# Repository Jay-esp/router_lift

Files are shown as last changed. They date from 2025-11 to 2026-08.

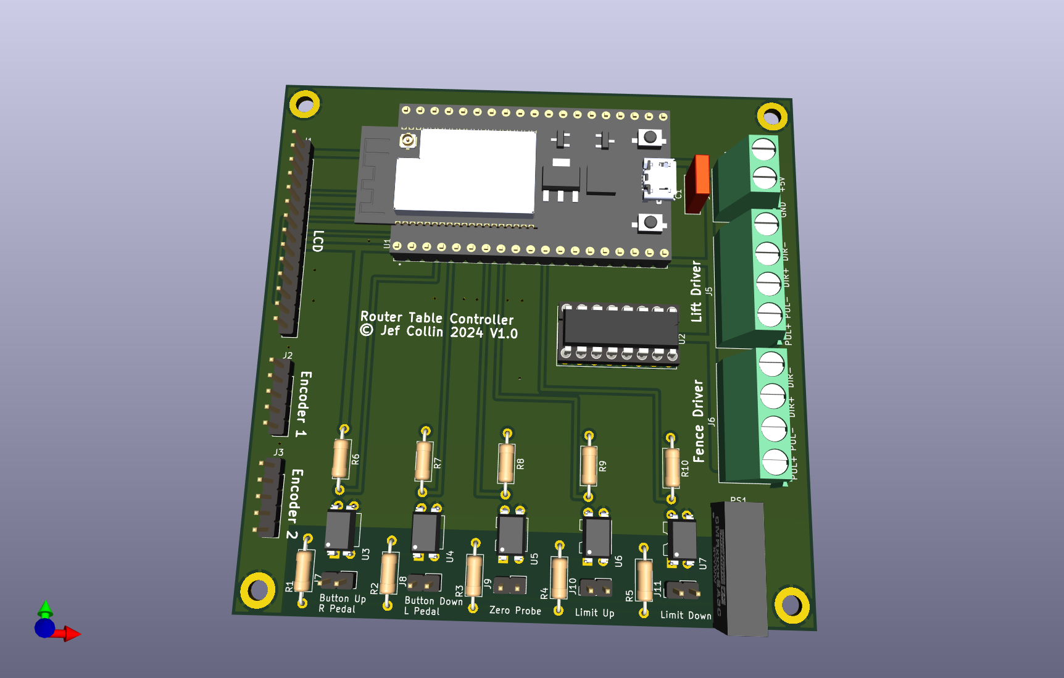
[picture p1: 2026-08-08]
router_table_1_0.png

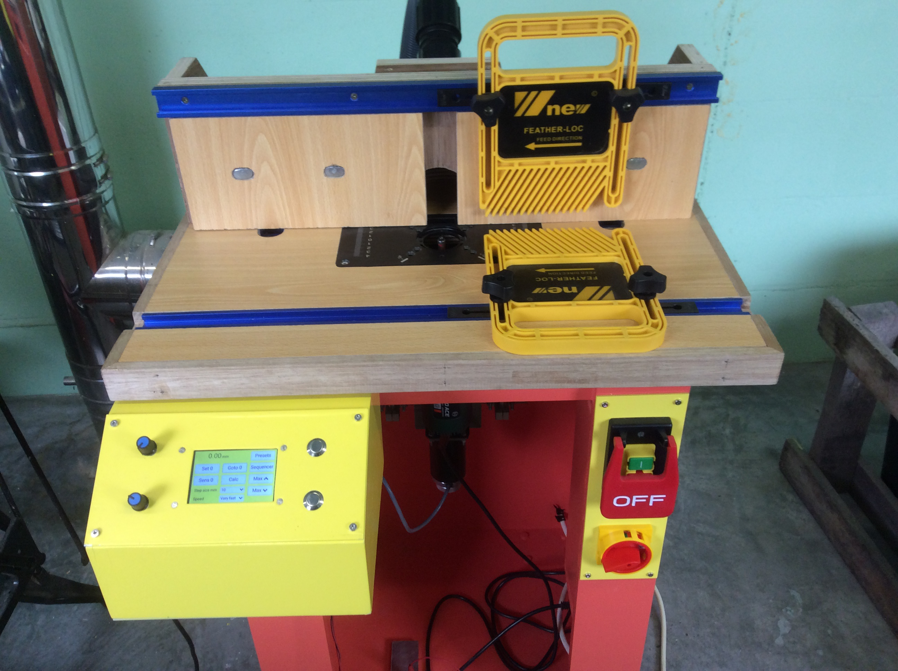
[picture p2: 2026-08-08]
IMG_5953.JPG

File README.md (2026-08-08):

# router_lift
Router table with electronic router lift using ESP32 and 3.5" touch screen

In 2020 I designed and built this router table with an electronic router lift. Since then i upgraded the electronics and rewrote the software, i made a YT video for it and published the design.

https://youtu.be/Isq1No5Fesk

Main features:

- Z height calibration using a sense block
- absolute positioning
- adjustable step size and plunge rate
- 25 presets
- 5 x 5 step sequencer
- dial a position of calculate a position

The electronics has a provision for a second stepper motor in case i later want to redesign it with a electronic fence.

Since all parts are made by hand there are no precise mechanical drawings but I included some freecad concept drawings.

Development in the Arduino 1 IDE in portable mode, uses FastAccelStepper 1.2.7 stepper driver library, LovyanGFX 1.2.9 graphics driver library and LVGL 9.5.0 GUI library.

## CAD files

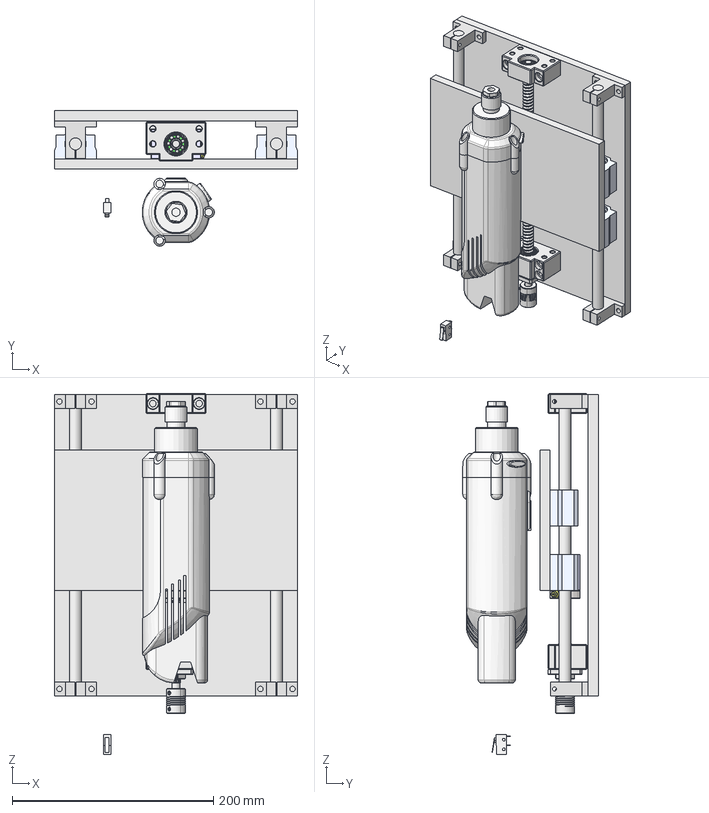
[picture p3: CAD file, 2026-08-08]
frees_lift2.FCStd
242.0 x 134.8 x 359.2 mm
SK12 SHAFT HOLDER
SK12 SHAFT HOLDER001
SK12 SHAFT HOLDER002
SK12 SHAFT HOLDER003
SC12UU
SC12UU001
SC12UU002
SC12UU003
BF10
BK10
SFU Ball Nut_1204-3
SFU1204 Washer Front
SFU1204 Washer Back
Grease Nipple A_A M6x1.00
Steel Ball_O 2.50
socket set screw cone point_iso_ISO 4027 - M3 x 5-C
socket set screw cone point_iso_ISO 4027 - M3 x 5-C001
socket set screw cone point_iso_ISO 4027 - M3 x 2.5-C
socket set screw cone point_iso_ISO 4027 - M3 x 2.5-C001
SFU1204-300_1204-300
CNC-F_N_CHINA_Domek kulickove matice
CHINA_Spojka pruzna_D19L25_6,35x8
LowerCap
Spilneus
Body-Grey
Body-Red
MICROSWITCH-NO

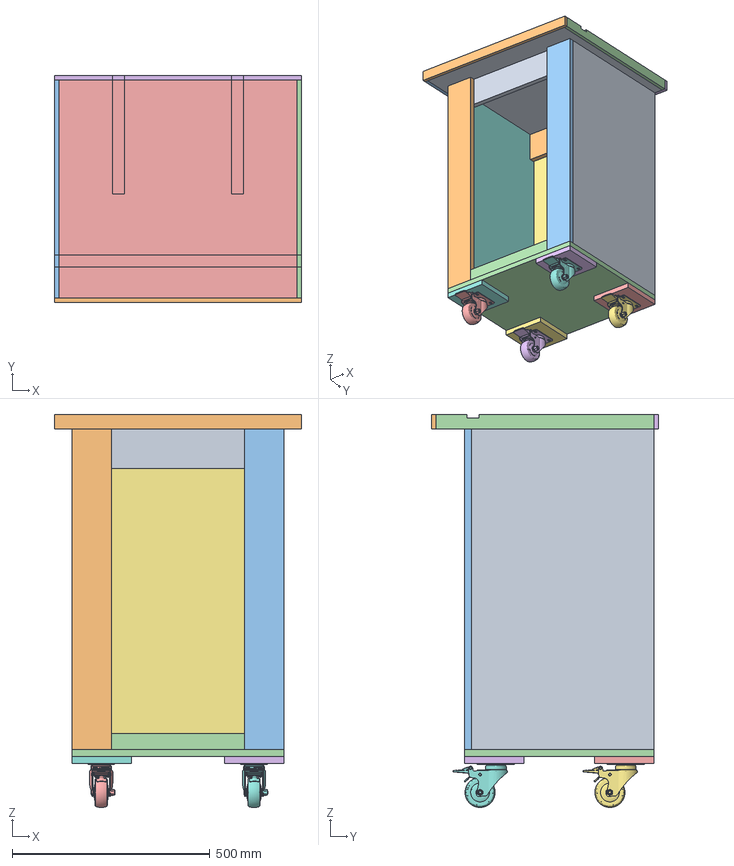
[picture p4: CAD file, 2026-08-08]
freestafel2.FCStd
624.0 x 574.0 x 992.5 mm
sSTL
sSTL002
sSTL003
sSTL001

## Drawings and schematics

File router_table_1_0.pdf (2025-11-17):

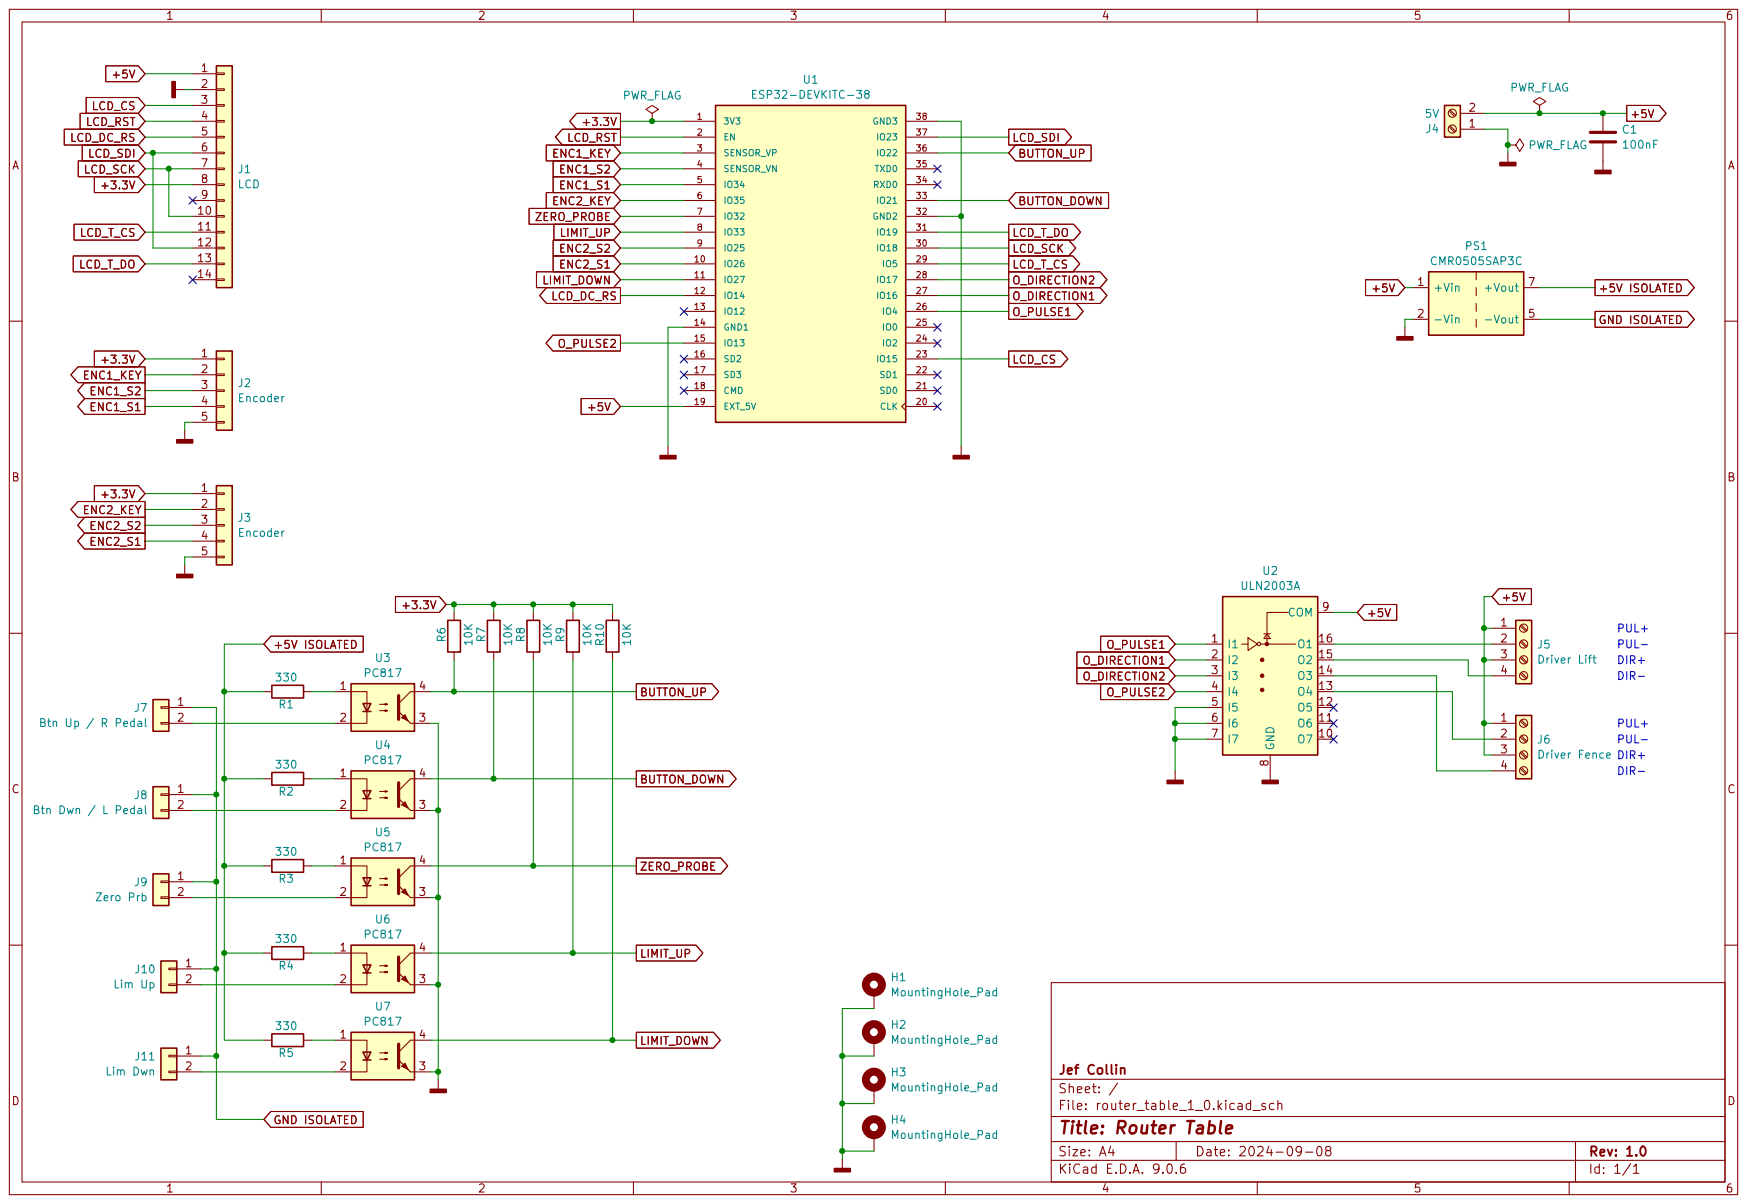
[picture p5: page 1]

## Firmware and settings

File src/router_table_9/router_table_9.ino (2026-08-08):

// router table controller
// (C) Jef Collin
// 2021..2026


// reminder: when lvgl library is updated, edit the config file!!!


// axis type 1204 4mm/revolution
// stepper driver set to 800 steps/revolution
// one step 0.005mm

// ENABLE connections to stepper driver can be left floating to enable permanent

// use normal closed limit switches

// todo


#include "FS.h"
#include <SPI.h>
#include <Preferences.h>
#include <lvgl.h>
#include "FastAccelStepper.h"
#include "esp_heap_caps.h"
#include "freertos/FreeRTOS.h"
#include "freertos/task.h"
#include <LovyanGFX.hpp>

extern lv_font_t dseg_60;
extern lv_font_t dseg_175;


#define TAB_MAIN_REF        0
#define TAB_MAINSUB_REF     1
#define TAB_ZERO_REF        2
#define TAB_PRESETS_REF     3
#define TAB_SEQUENCER_REF   4
#define TAB_EDIT_REF        5
#define TAB_CALC_REF        6
#define TAB_WAITBUSY_REF    7
#define TAB_ZOOM_REF        8
#define TAB_DIRECTENTRY_REF 9


// lvgl
#define LV_USE_DEBUG = 0;
// 3.5" display
#define TFT_HOR_RES 480
#define TFT_VER_RES 320
#define DRAW_BUF_SIZE (TFT_HOR_RES * TFT_VER_RES / 5 * (LV_COLOR_DEPTH / 8))

// stepper driver lift DM556 or equivalent
// always enabled
#define LIFT_STEP_DIR 16
#define LIFT_STEP_PULSE 4

// future expansion
// stepper driver fence
#define FENCE_STEP_DIR 17
#define FENCE_STEP_PULSE 13

// range limit in mm
#define MAX_ROUTER_POS 300

// limit switch polarity
// normal closed true
// normal open false
#define LIMIT_NC true

Preferences preferences;

FastAccelStepperEngine engine = FastAccelStepperEngine();
FastAccelStepper *stepper;

// default text for presets and sequences
#define PRESET_DEFAULT "Touch to edit"

// physical buttons/ pedals
#define buttonup_pin 22
#define buttondown_pin 21

// use alps or other decoder
//#define Use_Alps_Encoder false

// rotary encode io pins
#define Encoder_1_Pin1 34
#define Encoder_1_Pin2 39
#define Encoder_2_Pin1 26
#define Encoder_2_Pin2 25
#define Encoder_1_Key 36
#define Encoder_2_Key 35

// end of travel switches
#define endswitch_up 33
#define endswitch_down 27

// connection to zero sensor
#define zero_sensor 32

// rotary encoder
// No complete step yet.
#define DIR_NONE 0x0
// Clockwise step.
#define DIR_CW 0x10
// Anti-clockwise step.
#define DIR_CCW 0x20

//#if (Use_Alps_Encoder)
//// Alps EC11 encoder requires half step tables, others need full step
//#define R_START 0x0
//#define R_CCW_BEGIN 0x1
//#define R_CW_BEGIN 0x2
//#define R_START_M 0x3
//#define R_CW_BEGIN_M 0x4
//#define R_CCW_BEGIN_M 0x5
//
//const unsigned char ttable[6][4] = {
//  // R_START (00)
//  {R_START_M,            R_CW_BEGIN,     R_CCW_BEGIN,  R_START},
//  // R_CCW_BEGIN
//  {R_START_M | DIR_CCW, R_START,        R_CCW_BEGIN,  R_START},
//  // R_CW_BEGIN
//  {R_START_M | DIR_CW,  R_CW_BEGIN,     R_START,      R_START},
//  // R_START_M (11)
//  {R_START_M,            R_CCW_BEGIN_M,  R_CW_BEGIN_M, R_START},
//  // R_CW_BEGIN_M
//  {R_START_M,            R_START_M,      R_CW_BEGIN_M, R_START | DIR_CW},
//  // R_CCW_BEGIN_M
//  {R_START_M,            R_CCW_BEGIN_M,  R_START_M,    R_START | DIR_CCW},
//};
//
//#else
// Use the full-step state table (emits a code at 00 only)
#define R_CW_FINAL 0x1
#define R_CW_BEGIN 0x2
#define R_CW_NEXT 0x3
#define R_CCW_BEGIN 0x4
#define R_CCW_FINAL 0x5
#define R_CCW_NEXT 0x6
#define R_START 0x0

const unsigned char ttable[7][4] = {
  // R_START
  {R_START,    R_CW_BEGIN,  R_CCW_BEGIN, R_START},
  // R_CW_FINAL
  {R_CW_NEXT,  R_START,     R_CW_FINAL,  R_START | DIR_CW},
  // R_CW_BEGIN
  {R_CW_NEXT,  R_CW_BEGIN,  R_START,     R_START},
  // R_CW_NEXT
  {R_CW_NEXT,  R_CW_BEGIN,  R_CW_FINAL,  R_START},
  // R_CCW_BEGIN
  {R_CCW_NEXT, R_START,     R_CCW_BEGIN, R_START},
  // R_CCW_FINAL
  {R_CCW_NEXT, R_CCW_FINAL, R_START,     R_START | DIR_CCW},
  // R_CCW_NEXT
  {R_CCW_NEXT, R_CCW_FINAL, R_CCW_BEGIN, R_START},
};
//#endif

unsigned char Encoder_1_State = R_START;
unsigned char Encoder_2_State = R_START;

// track rotary encoder changes
int EncoderCounter1 = 0;
int EncoderCounter2 = 0;

long unsigned timer_encoderbutton1;
long unsigned timer_encoderbutton2;

boolean Encoder_Key1_Long_Press = false;
boolean Encoder_Key2_Long_Press = false;

// stepper commands for stepper task
typedef enum {
  CMD_NONE,
  CMD_SET_SPEED,
  CMD_SET_ACCEL,
  CMD_SET_CURRENTPOSITION,
  CMD_MOVE,
  CMD_MOVE_TO,
  CMD_STOP,
  CMD_EMERGENCY_STOP,
  CMD_SET_THIS_AS_CURRENT,
  CMD_ISRUNNING,
  CMD_GET_CURRENTPOSITION
} stepper_cmd_t;

typedef struct {
  stepper_cmd_t cmd;
  int32_t value;
} stepper_msg_t;

typedef struct {
  bool is_running;
} stepper_running_feedback_t;

typedef struct {
  int32_t current_position;
} stepper_position_feedback_t;

QueueHandle_t stepperQueue;
QueueHandle_t stepperRunningFeedbackQueue;
QueueHandle_t stepperPositionFeedbackQueue;

// state machine states sense zero
enum SenseZeroState {
  SENSE_ZERO_IDLE,
  SENSE_ZERO_INIT,
  SENSE_ZERO_CHECK_TOP_SWITCH,
  SENSE_ZERO_MOVE_DOWN,
  SENSE_ZERO_WAIT_DOWN,
  SENSE_ZERO_DEBOUNCE_DOWN,
  SENSE_ZERO_MOVE_UP,
  SENSE_ZERO_WAIT_UP,
  SENSE_ZERO_COMPLETE,
  SENSE_ZERO_ERROR
};

SenseZeroState senseZeroState = SENSE_ZERO_IDLE;
unsigned long senseZeroTimer = 0;

// state machine states for goto max top
enum GotoMaxTopState {
  GOTO_MAX_TOP_IDLE,
  GOTO_MAX_TOP_INIT,
  GOTO_MAX_TOP_CHECK_TOP_SWITCH,
  GOTO_MAX_TOP_MOVE_DOWN,
  GOTO_MAX_TOP_WAIT_DOWN,
  GOTO_MAX_TOP_DEBOUNCE_DOWN,
  GOTO_MAX_TOP_MOVE_UP,
  GOTO_MAX_TOP_WAIT_UP,
  GOTO_MAX_TOP_DEBOUNCE_UP,
  GOTO_MAX_TOP_MOVE_DOWN_FINAL,
  GOTO_MAX_TOP_WAIT_DOWN_FINAL,
  GOTO_MAX_TOP_DEBOUNCE_FINAL,
  GOTO_MAX_TOP_COMPLETE,
  GOTO_MAX_TOP_ERROR
};

GotoMaxTopState gotoMaxTopState = GOTO_MAX_TOP_IDLE;
unsigned long gotoMaxTopTimer = 0;

enum GotoMaxBottomState {
  GOTO_MAX_BOTTOM_IDLE,
  GOTO_MAX_BOTTOM_INIT,
  GOTO_MAX_BOTTOM_CHECK_BOTTOM_SWITCH,
  GOTO_MAX_BOTTOM_MOVE_UP,
  GOTO_MAX_BOTTOM_WAIT_UP,
  GOTO_MAX_BOTTOM_DEBOUNCE_UP,
  GOTO_MAX_BOTTOM_MOVE_DOWN,
  GOTO_MAX_BOTTOM_WAIT_DOWN,
  GOTO_MAX_BOTTOM_DEBOUNCE_DOWN,
  GOTO_MAX_BOTTOM_MOVE_UP_FINAL,
  GOTO_MAX_BOTTOM_WAIT_UP_FINAL,
  GOTO_MAX_BOTTOM_DEBOUNCE_FINAL,
  GOTO_MAX_BOTTOM_COMPLETE,
  GOTO_MAX_BOTTOM_ERROR
};

GotoMaxBottomState gotoMaxBottomState = GOTO_MAX_BOTTOM_IDLE;
unsigned long gotoMaxBottomTimer = 0;

enum MoveStepperState {
  MOVE_STEPPER_IDLE,
  MOVE_STEPPER_INIT,
  MOVE_STEPPER_START,
  MOVE_STEPPER_MOVING,
  MOVE_STEPPER_RECOVER_UP,
  MOVE_STEPPER_RECOVER_DOWN,
  MOVE_STEPPER_COMPLETE,
  MOVE_STEPPER_ERROR
};

MoveStepperState moveStepperState = MOVE_STEPPER_IDLE;
unsigned long moveStepperTimer = 0;
bool moveStepperDirectionUp = false;
float moveStepperTargetPosition = 0.0;
float moveStepperStepCount = 0.0;

String strbuf;
char printbuf[30];

// calculator
String calc_one = "0";
String calc_two = "0";
String calc_dec_one = "0";
String calc_dec_two = "0";
String calc_ops = "";
boolean calc_dec_active = false;

// direct entry
String direct_one = "0";
String direct_dec_one = "0";
boolean direct_dec_active = false;

// struct for preset and sequencer settings
struct SettingStructure {
  float setting_position;
  uint8_t setting_speed;
  String setting_info;
};

SettingStructure P_S_settings[50];

uint8_t presets_selected = 0;

// graphics lib configuration
class LGFX : public lgfx::LGFX_Device
{
    lgfx::Panel_ILI9488     _panel_instance;
    lgfx::Touch_XPT2046     _touch_instance;
    lgfx::Bus_SPI           _bus_instance;
  public:
    LGFX(void)
    {
      {
        auto cfg = _bus_instance.config();
        // SPI
        cfg.spi_host = SPI2_HOST;
        cfg.spi_mode = 0;
        cfg.freq_write = 60000000;
        cfg.freq_read  = 16000000;
        cfg.spi_3wire  = true;
        cfg.use_lock   = true;
        cfg.dma_channel = SPI_DMA_CH_AUTO;
        cfg.pin_sclk = 18;
        cfg.pin_mosi = 23;
        cfg.pin_miso = 19;
        cfg.pin_dc   = 14;
        _bus_instance.config(cfg);
        _panel_instance.setBus(&_bus_instance);
      }
      {
        auto cfg = _panel_instance.config();
        cfg.pin_cs           =    15;
        cfg.pin_rst          =    -1;
        cfg.pin_busy         =    -1;
        cfg.panel_width      =   320;
        cfg.panel_height     =   480;
        cfg.offset_x         =     0;
        cfg.offset_y         =     0;
        cfg.offset_rotation  =     0;
        cfg.dummy_read_pixel =     8;
        cfg.dummy_read_bits  =     1;
        cfg.readable         =  true;
        cfg.invert           = false;
        cfg.rgb_order        = false;
        cfg.dlen_16bit       = false;
        cfg.bus_shared       =  true;
        _panel_instance.config(cfg);
      }
      {
        // must be raw data point but not used if calibration is used
        auto cfg = _touch_instance.config();
        cfg.x_min      = 0;
        cfg.x_max      = 4000;
        cfg.y_min      = 0;
        cfg.y_max      = 4000;
        cfg.pin_int    = -1;
        cfg.bus_shared = true;
        cfg.offset_rotation = 0;
        // SPI
        cfg.spi_host = SPI2_HOST;
        cfg.freq = 1000000;
        cfg.pin_sclk = 18;
        cfg.pin_mosi = 23;
        cfg.pin_miso = 19;
        cfg.pin_cs   =  5;
        _touch_instance.config(cfg);
        _panel_instance.setTouch(&_touch_instance);
      }
      setPanel(&_panel_instance);
    }
};

LGFX TFT;

// callback routine for display
void my_disp_flush(lv_display_t* disp, const lv_area_t* area, uint8_t* px_map) {
  uint32_t w = (area->x2 - area->x1 + 1);
  uint32_t h = (area->y2 - area->y1 + 1);
  lv_draw_sw_rgb565_swap(px_map, w * h);
  TFT.startWrite();
  TFT.pushImageDMA(area->x1, area->y1, w, h, (uint16_t*)px_map);
  TFT.endWrite();
  lv_disp_flush_ready(disp);
}

// two buffer system
void *draw_buf_1;
void *draw_buf_2;

static lv_display_t *disp;

uint16_t setting_calibration_data[8];
uint8_t calDataOK = 0;

String setting_sequencer_info[5];


unsigned long buttonUpPressTime = 0;
unsigned long buttonDownPressTime = 0;
bool buttonUpWasPressed = false;
bool buttonDownWasPressed = false;
bool continuousMoveActive = false;
int8_t continuousMoveDirection = 0;
unsigned long continuousMoveLastStep = 0;
unsigned long continuousMoveInterval = 50; // ms between steps for continuous movement
unsigned long lastContinuousStepTime = 0;


float router_position = 0.0;
float router_old_position = 0;
float newposition = 0;
boolean position_valid = false;
boolean router_cancel = false;
int8_t router_return_from_busy = -1;

// nr of steps per rev / distance per rev in mm
float stepfactor = 800 / 4;

// startup selections for step size and plunge rate
uint8_t router_stepsize = 2;
uint8_t router_speed = 2;

uint8_t error_number = 0;

uint8_t zoomreturnscreen = 0;

// timers
unsigned long LVGL_Timer;

// lvgl variables
static lv_obj_t *tabview;

static lv_obj_t *tabmain;
static lv_obj_t *tabmainsub;
static lv_obj_t *tabzero;
static lv_obj_t *tabpresets;
static lv_obj_t *tabsequencer;
static lv_obj_t *tabedit;
static lv_obj_t *tabcalc;
static lv_obj_t *tabwaitbusy;
static lv_obj_t *tabzoom;
static lv_obj_t *tabdirectentry;

static lv_obj_t * btn_pos_small;
static lv_obj_t * btn_pos_small_label;

static lv_obj_t * btn_pos_small2;
static lv_obj_t * btn_pos_small_label2;

static lv_obj_t * btn_pos_large;
static lv_obj_t * btn_pos_large_label;

static lv_obj_t * btn_gotozero;
static lv_obj_t * btn_setzero;
static lv_obj_t * btn_findzero;
static lv_obj_t * btn_nextmain;
static lv_obj_t * btn_presets;
static lv_obj_t * btn_sequencer;
static lv_obj_t * btn_gomaxup;
static lv_obj_t * btn_gomaxdown;
static lv_obj_t * btn_cancelmove;
static lv_obj_t * btn_startzero;
static lv_obj_t * btn_cancelzero;
static lv_obj_t * ddlist_stepsize;
static lv_obj_t * ddlist_speed;
static lv_obj_t * roller;

static lv_obj_t * btn_calculator;
static lv_obj_t * btn_gotocalc;

static lv_obj_t * btn_preset_next;
static lv_obj_t * btn_preset_previous;

static lv_obj_t * btn_preset_0;
static lv_obj_t * btn_preset_1;
static lv_obj_t * btn_preset_2;
static lv_obj_t * btn_preset_3;
static lv_obj_t * btn_preset_4;

static lv_obj_t * btn_sequencer_next;
static lv_obj_t * btn_sequencer_previous;

lv_style_t btn_style1_selected;

lv_obj_t * img_busy_main;
lv_obj_t * img_busy_mainsub;
lv_obj_t * img_busy_zoom;

static lv_obj_t * lbl_pre_title1;
static lv_obj_t * lbl_pre_title2;
static lv_obj_t * lbl_pre_title3;
static lv_obj_t * lbl_pre_title4;
static lv_obj_t * lbl_pre_title5;

static lv_obj_t * lbl_pre30;
static lv_obj_t * lbl_pre31;
static lv_obj_t * lbl_pre32;
static lv_obj_t * lbl_pre33;
static lv_obj_t * lbl_pre34;

static lv_obj_t * lbl_speed30;
static lv_obj_t * lbl_speed31;
static lv_obj_t * lbl_speed32;
static lv_obj_t * lbl_speed33;
static lv_obj_t * lbl_speed34;

static lv_obj_t * lbl_tag30;
static lv_obj_t * lbl_tag31;
static lv_obj_t * lbl_tag32;
static lv_obj_t * lbl_tag33;
static lv_obj_t * lbl_tag34;

static lv_obj_t * lbl_mark100;
static lv_obj_t * lbl_mark101;
static lv_obj_t * lbl_mark102;
static lv_obj_t * lbl_mark103;
static lv_obj_t * lbl_mark104;

static lv_obj_t * lbl_pre100;
static lv_obj_t * lbl_pre101;
static lv_obj_t * lbl_pre102;
static lv_obj_t * lbl_pre103;
static lv_obj_t * lbl_pre104;

static lv_obj_t * lbl_speed100;
static lv_obj_t * lbl_speed101;
static lv_obj_t * lbl_speed102;
static lv_obj_t * lbl_speed103;
static lv_obj_t * lbl_speed104;
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
void loop() {
  // check for pending error messages
  if (error_number > 0) {
    show_error_message();
  }

  if (!is_motor_running() and moveStepperState == MOVE_STEPPER_IDLE and senseZeroState == SENSE_ZERO_IDLE and gotoMaxBottomState == GOTO_MAX_BOTTOM_IDLE and gotoMaxTopState == GOTO_MAX_TOP_IDLE) {
    check_actions_encoder1();
    check_actions_encoder2();
    check_actions_key1();
    check_actions_key2();
    check_buttons_and_move();
  }

  // sense zero state machine
  switch (senseZeroState) {
    case SENSE_ZERO_IDLE:
      break;

    case SENSE_ZERO_INIT:
      router_cancel = false;
      router_return_from_busy = -1;
      show_busy_screen();
      error_number = 0;
      position_valid = false;
      update_controls();
      // slowest speed
      setspeed(0);
      // reset current position
      send_command_to_task(CMD_EMERGENCY_STOP, 0);
      senseZeroState = SENSE_ZERO_CHECK_TOP_SWITCH;
      break;

    case SENSE_ZERO_CHECK_TOP_SWITCH:
      if (check_endswitch_up() or digitalRead(zero_sensor) == 0) {
        // at max up position or sensor already detected, need to move down 20mm first
        send_command_to_task(CMD_MOVE, -20 * stepfactor);
        senseZeroState = SENSE_ZERO_WAIT_DOWN;
      } else {
        // not at top, proceed to move up
        send_command_to_task(CMD_MOVE, MAX_ROUTER_POS * stepfactor);
        senseZeroState = SENSE_ZERO_WAIT_UP;
      }
      break;

    case SENSE_ZERO_WAIT_DOWN:
      if (router_cancel) {
        invalidate_position();
        senseZeroState = SENSE_ZERO_COMPLETE;
      } else if (!check_endswitch_up() and digitalRead(zero_sensor) != 0) {
        // switch and sensor cleared, move completed
        send_command_to_task(CMD_EMERGENCY_STOP, 0);
        senseZeroTimer = millis();
        senseZeroState = SENSE_ZERO_DEBOUNCE_DOWN;
      } else if (check_endswitch_down()) {
        // reached the bottom end switch
        invalidate_position();
        error_number = 2;
        senseZeroState = SENSE_ZERO_COMPLETE;
      } else if (!is_motor_running()) {
        // move is completed without clearing the end switch and/or sensor
        if (check_endswitch_up()) {
          error_number = 1;
        } else if (digitalRead(zero_sensor) == 0) {
          error_number = 8;
        }
        invalidate_position();
        senseZeroState = SENSE_ZERO_COMPLETE;
      }
      break;

    case SENSE_ZERO_DEBOUNCE_DOWN:
      // recheck sensors after timeout
      if (millis() - senseZeroTimer >= 100) {
        // restart
        senseZeroState = SENSE_ZERO_CHECK_TOP_SWITCH;
      }
      break;

    case SENSE_ZERO_WAIT_UP:
      if (router_cancel) {
        invalidate_position();
        senseZeroState = SENSE_ZERO_COMPLETE;
      } else if (digitalRead(zero_sensor) == 0) {
        // Zero sensor triggered
        send_command_to_task(CMD_EMERGENCY_STOP, 0);
        position_valid = true;
        senseZeroState = SENSE_ZERO_COMPLETE;
      } else if (check_endswitch_up()) {
        // reached top switch without finding sensor
        invalidate_position();
        error_number = 3;
        senseZeroState = SENSE_ZERO_COMPLETE;
      }
      break;

    case SENSE_ZERO_COMPLETE:
      router_position = 0;
      lv_tabview_set_act(tabview, TAB_MAIN_REF, LV_ANIM_OFF);
      update_position();
      senseZeroState = SENSE_ZERO_IDLE;
      update_controls();
      break;

    case SENSE_ZERO_ERROR:
      // handle error state if needed
      senseZeroState = SENSE_ZERO_COMPLETE;
      break;
  }

  // state machine states for goto max top
  switch (gotoMaxTopState) {
    case GOTO_MAX_TOP_IDLE:
      break;

    case GOTO_MAX_TOP_INIT:
      router_cancel = false;
      router_return_from_busy = -1;
      show_busy_screen();
      error_number = 0;
      position_valid = false;
      update_controls();
      setspeed(2);
      send_command_to_task(CMD_EMERGENCY_STOP, 0);
      gotoMaxTopState = GOTO_MAX_TOP_CHECK_TOP_SWITCH;
      break;

    case GOTO_MAX_TOP_CHECK_TOP_SWITCH:
      if (check_endswitch_up()) {
        // at max up position, need to move down 20mm first
        send_command_to_task(CMD_MOVE, -20 * stepfactor);
        gotoMaxTopState = GOTO_MAX_TOP_WAIT_DOWN;
      } else {
        // not at top, proceed to move up
        send_command_to_task(CMD_MOVE, MAX_ROUTER_POS * stepfactor);
        gotoMaxTopState = GOTO_MAX_TOP_WAIT_UP;
      }
      break;

    case GOTO_MAX_TOP_WAIT_DOWN:
      if (router_cancel) {
        invalidate_position();
        gotoMaxTopState = GOTO_MAX_TOP_ERROR;
      } else if (!check_endswitch_up()) {
        // switch released, move completed
        send_command_to_task(CMD_EMERGENCY_STOP, 0);
        gotoMaxTopTimer = millis();
        gotoMaxTopState = GOTO_MAX_TOP_DEBOUNCE_DOWN;
      } else if (check_endswitch_down()) {
        // reached the bottom end switch
        invalidate_position();
        error_number = 2;
        gotoMaxTopState = GOTO_MAX_TOP_ERROR;
      } else if (!is_motor_running()) {
        // move is completed without clearing the end switch
        invalidate_position();
        error_number = 1;
        gotoMaxTopState = GOTO_MAX_TOP_ERROR;
      }
      break;

    case GOTO_MAX_TOP_DEBOUNCE_DOWN:
      if (millis() - gotoMaxTopTimer >= 100) {
        // restart
        gotoMaxTopState = GOTO_MAX_TOP_CHECK_TOP_SWITCH;
      }
      break;

    case GOTO_MAX_TOP_WAIT_UP:
      if (router_cancel) {
        invalidate_position();
        gotoMaxTopState = GOTO_MAX_TOP_ERROR;
      } else if (check_endswitch_up()) {
        // reached top switch
        send_command_to_task(CMD_EMERGENCY_STOP, 0);
        gotoMaxTopTimer = millis();
        gotoMaxTopState = GOTO_MAX_TOP_DEBOUNCE_UP;
      } else if (!is_motor_running()) {
        invalidate_position();
        error_number = 4;
        gotoMaxTopState = GOTO_MAX_TOP_ERROR;
      }
      break;

    case GOTO_MAX_TOP_DEBOUNCE_UP:
      if (millis() - gotoMaxTopTimer >= 100) {
        if (!check_endswitch_up()) {
          invalidate_position();
          error_number = 4;
          gotoMaxTopState = GOTO_MAX_TOP_ERROR;
        } else {
          // Move down 20mm to clear top sensor
          send_command_to_task(CMD_MOVE, -20 * stepfactor);
          gotoMaxTopState = GOTO_MAX_TOP_WAIT_DOWN_FINAL;
        }
      }
      break;

    case GOTO_MAX_TOP_WAIT_DOWN_FINAL:
      if (router_cancel) {
        invalidate_position();
        gotoMaxTopState = GOTO_MAX_TOP_ERROR;
      } else if (!check_endswitch_up()) {
        // switch released, move completed
        send_command_to_task(CMD_EMERGENCY_STOP, 0);
        gotoMaxTopTimer = millis();
        gotoMaxTopState = GOTO_MAX_TOP_DEBOUNCE_FINAL;
      } else if (check_endswitch_down()) {
        // reached the bottom end switch
        invalidate_position();
        error_number = 2;
        gotoMaxTopState = GOTO_MAX_TOP_ERROR;
      } else if (!is_motor_running()) {
        invalidate_position();
        error_number = 1;
        gotoMaxTopState = GOTO_MAX_TOP_ERROR;
      }
      break;

    case GOTO_MAX_TOP_DEBOUNCE_FINAL:
      if (millis() - gotoMaxTopTimer >= 100) {
        if (check_endswitch_up()) {
          invalidate_position();
          error_number = 1;
          gotoMaxTopState = GOTO_MAX_TOP_ERROR;
        }
        else {
          gotoMaxTopState = GOTO_MAX_TOP_COMPLETE;
        }
      }
      break;

    case GOTO_MAX_TOP_COMPLETE:
      router_position = 0;
      lv_tabview_set_act(tabview, TAB_MAIN_REF, LV_ANIM_OFF);
      update_position();
      gotoMaxTopState = GOTO_MAX_TOP_IDLE;
      update_controls();
      break;

    case GOTO_MAX_TOP_ERROR:
      // Handle error state if needed
      gotoMaxTopState = GOTO_MAX_TOP_COMPLETE;
      break;
  }

  // state machine states for goto max bottom
  switch (gotoMaxBottomState) {
    case GOTO_MAX_BOTTOM_IDLE:
      break;

    case GOTO_MAX_BOTTOM_INIT:
      router_cancel = false;
      router_return_from_busy = -1;
      show_busy_screen();
      error_number = 0;
      position_valid = false;
      update_controls();
      setspeed(2);
      send_command_to_task(CMD_EMERGENCY_STOP, 0);
      gotoMaxBottomState = GOTO_MAX_BOTTOM_CHECK_BOTTOM_SWITCH;
      break;

    case GOTO_MAX_BOTTOM_CHECK_BOTTOM_SWITCH:
      if (check_endswitch_down()) {
        // at max down position, need to move up 20mm first
        send_command_to_task(CMD_MOVE, 20 * stepfactor);
        gotoMaxBottomState = GOTO_MAX_BOTTOM_WAIT_UP;
      } else {
        // not at bottom, proceed to move down
        send_command_to_task(CMD_MOVE, -1 * MAX_ROUTER_POS * stepfactor);
        gotoMaxBottomState = GOTO_MAX_BOTTOM_WAIT_DOWN;
      }
      break;
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
